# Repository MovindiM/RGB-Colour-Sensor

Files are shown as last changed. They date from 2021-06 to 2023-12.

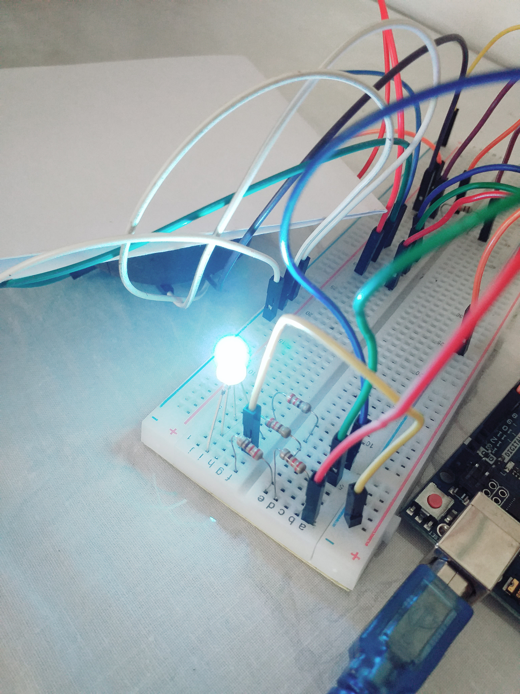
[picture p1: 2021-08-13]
Physical_Arduino_Device/photos/White.jpg

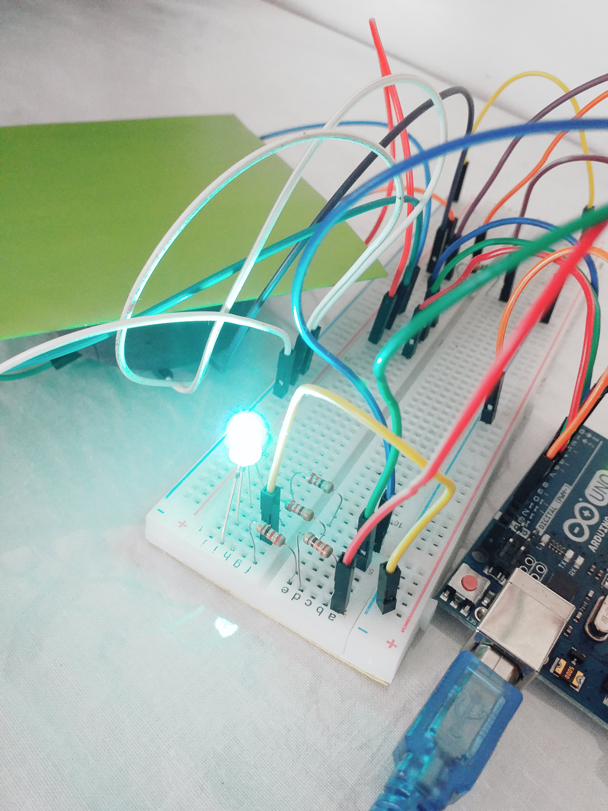
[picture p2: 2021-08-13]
Physical_Arduino_Device/photos/Green.jpg

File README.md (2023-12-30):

# RGB Colour Sensor

## Semester 2 Lab Project - GRP 14
Department of Electronic and Telecommunication Engineering  
University of Moratuwa

Welcome to the RGB Colour Sensor project repository! This project focuses on designing and implementing a colour sensor capable of detecting the colour on a surface and providing its R, G, and B values. The sensor is based on the RGB model and can find applications in industrial, medical, and security systems.

## Project Overview

In this project, we aimed to develop a versatile colour sensor with the following features:

- **Calibration Stage:** The sensor includes a calibration stage to accommodate alterations in lighting conditions.

- **Modes:**
  - **Calibration Mode (a):** Allows the user to perform calibration at the beginning.
  - **Sensing Mode (b):** Enables the sensor to detect and output the R, G, and B values of the colour on a surface.
  - **LED Illumination Mode (c):** Lights up an RGB LED based on user-defined R, G, and B values.

## Getting Started

To get started with the RGB Colour Sensor, follow these steps:

1. **Clone the Repository:**
   ```bash
   git clone https://github.com/your-username/RGB-Colour-Sensor.git

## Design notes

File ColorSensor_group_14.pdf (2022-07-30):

University of Moratuwa

EN 1093 – Laboratory Practice I

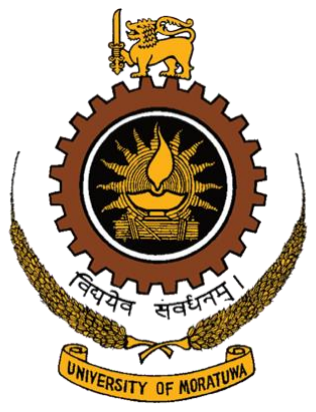
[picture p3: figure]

RGB Colour Sensor

Supervisor- Achintha Wijesinghe

This is submitted as a partial fulfillment for the module EN1093: Laboratory Practice I Department of Electronic and Telecommunication Engineering University of Moratuwa

16

th August 2021

Loshanan M. | 190363X
Luxshan S. | 190364C
Mathotaarachchi M.M. | 190388D
Mokeeshan V. | 190395V

1 | P a g e

### Abstract

Coloris- the RGB colour sensor is device that can detect the colour of any given surface. And there is a mode to light the colour using RGB LED with user given R, G, B values. The key idea is coloured objects reflect their own colour and absorb all others. This project is done by lighting a colour light source and analysing the reflected colour light from the given surface. This colour sensor is designed using ATMega microcontroller. For an input of unknown coloured surface, the result would be in the format of RGB colour model. And the colour of that surface is detected as the most dominating colour among red, green, and blue. Also, the result of RGB colour mixture can be visualised from this product using a single RGB LED and with 16*2 LCD Display.

### Table of Contents

Abstract | 1
List of Tables | 1
List of Figures | 1
1. Introduction | 2
1.1 | Task | 2
1.2 | Specifications | 2
1.3 | Scientific Literature | 2
2. Methods | 3
2.1 | Arduino 3
2.2 | Coding ATMEGA microcontroller....3
2.2.1 | Creating a function for the
Keypad: | 3
2.2.2 | Creating functions for the LCD
display and the I2C | 3

2.2.3 Creating functions for different
tasks of the algorithm | 3
2.3 | PCB Design | 4
2.3.1 | Electronic components | 4
2.3.2 | Connectors | 4
2.3.3 | PCB information | 4
2.3.4 | Main Circuit Board | 5
2.4 | Enclosure design | 5
3. Results | 6
4. Discussion | 7
5. Acknowledgement | 8
6. References | 8
7. Appendices | 9
7.1 | Appendix I-Circuit Diagram | 9
7.2 | Appendix II- PCB design | 9
7.3 | Appendix III- Enclosure Design .....10
7.4 | Appendix IV- Output | 11
7.5 | Appendix V-Algorithm | 12
| 12
7.6 | GitHub repository link- RGB Sensor
project13
7.7 Appendix VI-Atmega code | 13

### List of Tables

Table 3.1:Sensor part Readings | 6

### List of Figures

Figure 1.1:theory of colour detection | 2
Figure 2.1:LCD Display Views | 3
Figure 2.2:LDR reading principle | 4
Figure 3.1:LCD Display Views | 6
Figure 3.2: Linear mapping concept | 6
Figure 7.1:Circuit diagram with ATMega328 ..9
Figure 7.2:Schematic of the main PCB | 9
Figure 7.3:Main PCB top view (in Altium
software) | 9
Figure 7.4:PCB top layer | 9
Figure 7.5:PCB bottom layer | 9
Figure 7.6:3D view of PCB | 9
Figure 7.7:Enclosure Top view | 10
Figure 7.8:Enclosure back view | 10
Figure 7.9:Enclosure Interior-bottom part....10 Figure 7.10:Enclosure Interior top part.........10
Figure 7.11:Results- Green color | 11
Figure 7.12:Results- Blue color | 11
Figure 7.13:Results- Red Color | 11
Figure 7.14:Results- White Color | 11
Figure 7.15:Results- Violet Color | 11

### 1. Introduction

Colour detection is one of the main principles which are used to evaluate the properties of a material. Colour detection sensors are used in many industries such as food and beverage, automotive and manufacturing. In this project Coloris-the RGB colour sensor is designed using three LEDs and an LDR. It detects the colour of any surface and can light up the colour that a user wants.

The fundamental, used in this project is, objects appear coloured because they absorb some colours and reflect some other colours into human eyes. In this project colour sensor is developed by measuring the density of reflected colour light by the given-coloured object.

The most common RGB colour model is used throughout this project.

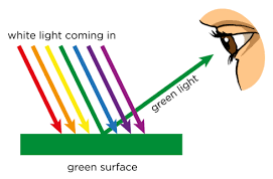
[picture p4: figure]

Figure 1.1:theory of colour detection

### 1.1 Task

- The colour sensor should sense and output the colour of a given surface.
- A calibration stage is allowed before sensing.
- There should be a mode to light a RGB LED for user given red, green, and blue values.

### 1.2 Specifications

- The sensor should contain
- a/ many LDR
- a keypad
- an LCD display
- PCBs
- enclosure
- RGB LED
- Product should be able to handle alternations in lighting conditions
- | ATMega | microcontrollers | are
recommended to use

### 1.3 Scientific Literature

After the problem was identified clearly a flowchart was developed to show objectives of the project. After that a circuit is designed using Arduino and it was coded properly. Then the circuit was developed by using physical simulations to have better results.

Then the project moved from Arduino to single ATMega microcontroller circuit. The basics of coding a microcontroller, were learned before moving the simulation to ATMega. Both ATMega and Arduino simulations were done by Proteus 8 software. Required PCB is designed using Altium software. Then using the dimensions of the PCB, the 3D enclosure was designed by Solidworks.

### 2. Methods

### 2.1 Arduino

At the beginning this project is designed using Arduino Uno. Circuits were designed in this stage and the simulations were done using Proteus software.

First LCD display is connected to Arduino and coded for displaying texts in that LCD display. Then the keypad is connected to Arduino for the purpose of changing the modes and entering the inputs for user input mode. Keypad library is used to code Arduino for using this matrix style keypad.

Next the main core part is developed using red, green, and blue LEDs and a LDR for the purpose of doing calibration and sensing. Since the pin connected to LDR should be an input pin, it was connected to an Analog pin of the Arduino.

Then there are no more free pins in Arduino to connect an RGB LED for user input mode. So, an I2C module is used to connect LCD display for minimising the required number of pins. Only two pins are enough for the working of the LCD display if the I2C is used, otherwise it requires 6 pins to connect. Then the RGB LED was attached with three PWM pins in Arduino, and the Arduino code was fully finalized.

Figure 2.1:LCD Display Views

### 2.2 Coding ATMEGA

microcontroller

As ATMEGA328P is simpler to use, with the usage of 8bit and 16bit instead of 32/64bit which are more complicated. So, here the ATMega microcontroller was used as the final design and programmed it using C.

basic libraries in C that used here.

#include <avr/io.h>

#include <util/delay.h>

#include <stdio.h>

#include <string.h>

#include <stdlib.h>

#include <math.h>

2.2.1 Creating a function for the Keypad:

- The concept behind this task is when a key is pressed the relevant circuit is completed. First the pin connected to 1

st row is made high. Then it’ll check if any of the pins connected to the columns are at the high level. After a delay of 40 ms it’ll do the same for the 2

nd row. | Just like this process takes
place in all 4 rows continuously. | If it
recognizes that a column is high, then we get the corresponding key as input.

2.2.2 Creating functions for the LCD display and the I2C

- Used datasheets and made functions for LCD and I2C separately.

2.2.3 Creating functions for different tasks of the algorithm

- As this code must do various number of
tasks, | here | several | numbers | of
functions are created earlier part of the code and used in main part. The advantages of using functions are
- Code became more simple and easily understandable.
- reduce the length of the main part of the code.
- Detecting the errors was easy.

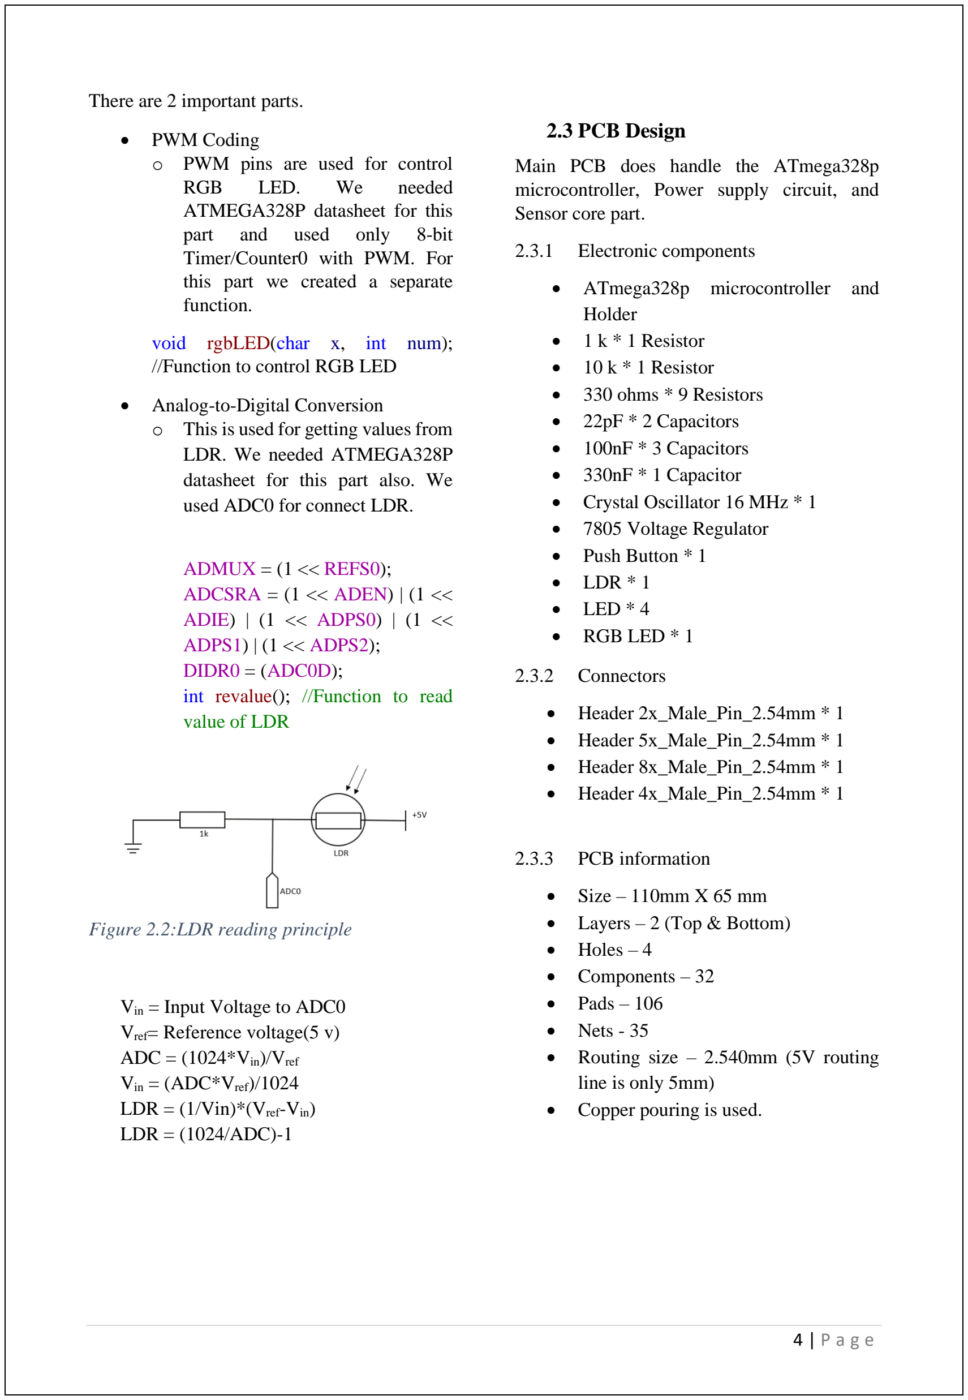
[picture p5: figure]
There are 2 important parts.; • PWM Coding • PWM pins are used for control; RGB; LED.; needed; ATMEGA328P datasheet for this; part; and; used; only; 8-bit; Timer/Counter0 with PWM. For this part we created a separate function.; void rgbLED(char x, int num); //Function to control RGB LED; • Analog-to-Digital Conversion • This is used for getting values from LDR. We needed ATMEGA328P datasheet for this part also. We used ADC0 for connect LDR.; ADMUX = (1 << REFS0); ADCSRA = (1 << ADEN) | (1 << ADIE) | (1 << ADPS0) | (1 << ADPS1) | (1 << ADPS2); DIDR0 = (ADC0D); int revalue(); //Function to read value of LDR; Figure 2.2:LDR reading principle; Vin = Input Voltage to ADC0 Vref= Reference voltage(5 v) ADC = (1024*Vin)/Vref Vin = (ADC*Vref)/1024 LDR = (1/Vin)*(Vref-Vin) LDR = (1024/ADC)-1; 2.3 PCB Design; Main PCB does handle the ATmega328p; Sensor core part.; Electronic components; • ATmega328p microcontroller and Holder; • 1 k * 1 Resistor; • 10 k * 1 Resistor; • 330 ohms * 9 Resistors; • 22pF * 2 Capacitors; • 100nF * 3 Capacitors; • 330nF * 1 Capacitor; • Crystal Oscillator 16 MHz * 1; • 7805 Voltage Regulator; • Push Button * 1; • LDR * 1; • LED * 4; • RGB LED * 1; Connectors; • Header 2x_Male_Pin_2.54mm * 1; • Header 5x_Male_Pin_2.54mm * 1; • Header 8x_Male_Pin_2.54mm * 1; • Header 4x_Male_Pin_2.54mm * 1; PCB information; • Size – 110mm X 65 mm; • Layers – 2 (Top & Bottom); • Holes – 4; • Components – 32; • Pads – 106; • Nets - 35; • Routing size – 2.540mm (5V routing line is only 5mm); • Copper pouring is used.

microcontroller, Power supply circuit, and

2.3.4 Main Circuit Board

This mainly includes the ATmega328p microcontroller, Power supply (5V Power regulator), and Sensor core part. ATmega328p microcontroller takes signals from LDR and executes appropriate color in the RGB led.

In this PCB power supply unit, first, we connect a 9V battery to the 2x_Male header pin. Then the regulating circuit converts this 9V to 5V in this purpose we use a 7805-voltage regulator, 330nF, 100nF capacitors, LED, and 330-ohm resistor. In the ATmega328p microcontroller part, there is a 22pF two capacitors, one 16 MHz crystal oscillator, one 100nF capacitor 10k resistor, and a reset button for the working
purpose | of | this | microcontroller. | This
microcontroller should be programmed by the FTDI connector with the Atmel studio programming Code for the working conditions. 8x_Male_Pin header is used to connect the keypad and the 4x_Male_Pin header is used to connect the LCD display I2C module with the main PCB board.

In the Sensor core part, here used red, green, blue led lights separately, a LDR, four 330 ohms resistors, and one 1K resistor. It located as LEDs in the circumference of the circle (1mm radius) in equal gaps. LDR is in the centre part of the circle, in the core part. two 330 ohms resistors cascade in the red LED. Because this RED color LED voltage drops (1.7V – 2V) is lower than other two-color LEDs. Also,330-ohm is connected resistors series with each green and blue LED. When the working time, the LEDs blink one by one, and the data from the color sheet is captured to the LDR in each LED blink time. And this analog
data | sends | through | the | Atmega328p
Microcontroller for identifying purposes. In the Output, RGB single LED, similarly connect their colors with 330 ohms resistors and this LED indicates the correct color of the object in the programming time.

### 2.4 Enclosure design

As a product to present in the market it is important to design an enclosure which contains the availability of fixing all the parts in an attractive and economical manner. Here for the color sensor, the enclosure was designed using Solidworks. As PCB contains both sensor part and main circuit in on a single circuit board, enclosure is in a step-down manner which will help to increase the accuracy of color sensor. After the development of body, the downloaded build-up components of 16*2 LCD Display, 4*4 Keypad and 9V battery holder and the relevant measures and spaces are added to the body. And at finally by using assembly feature of solidworks all the components were assembled as one product-Coloris Color Sensor.

The key features of the enclosure are:

- Length=210mm
- Width=120mm
- Hight=49mm
- Thickness= 2mm-5mm
- Density = 1.30 grams per cubic centimetre
- Mass = 569.99 grams
- Volume = 438.46 cubic centimetres
- | Surface | area | = | 1789.41 | square
centimetres
- material –PVC rigid
- Body color-Blue

Here as a color sensor enclosure, it must be a resistant for UV light reflection to avoid unnecessary destruction for LDR reading. So here PVC rigid material is used which is highly resistant for UV light. And more than that at the surrounding of sensor part there is black color to reduce the effect of light reflection in the reading of LDR. And finally, to present as a good outlooking device blue color is applied to the enclosure.

### 3. Results

In the working condition of the project first, LCD display shows a welcome message and then it shows operation Modes. The keypad keys show the corresponding operating modes

A – Calibration Mode

B – Sensing Mode

C – Input Keypad Values Mode

D – Reset Mode

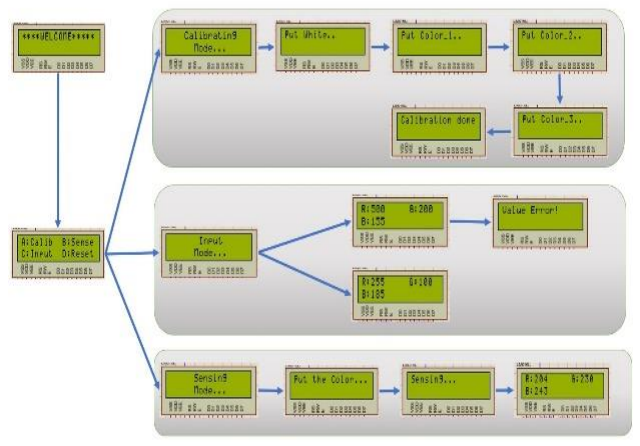
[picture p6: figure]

First, when Press “A” in the Keypad, the calibration mode will on.

Here it’ll calibrate the color cards. First, with the white color card, the sensor takes red, green, blue values to the system. Similarly, with the sequence of red color card, green color card, and the blue color card the red, green, blue values will be deducted by the system in the early stage. Then we linearly mapping (Voltage α light density) these values to get white array values and black array values. Here the below picture shows our mapping graph diagram.

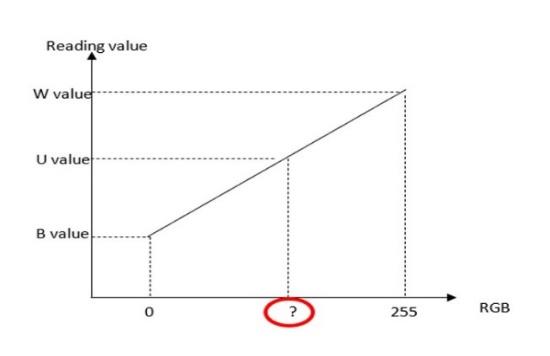
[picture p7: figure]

Figure 3.2: Linear mapping concept

According to the reading, white array red, green, and blue values are 781, 792, 625, and black array red, green, and blue values are 259, 389, 227. Then our calibration part is done.

After that press B in the Keypad to go the Sensing Mode.

Here the device will run with various of color cards to check the output. First, check the red color card in this time Lcd display shows the corresponding red, green, blue values are 223,27,41 in the 8-bit form. And the output RGB led blinks red color to indicate that color card. Similarly, check is done with green color card, blue color card, and violet color card their details are below in the table.

Table 3.1:Sensor part Readings

Color card | Red value | Green value | Blue value | RGB led blink color
Red | 223 | 27 | 41 | Red
Green | 108 | 191 | 50 | Green
Blue | 0 | 43 | 169 | Blue
White | 239 | 255 | 255 | White
Violet | 107 | 25 | 108 | Violet

Then press C in the Keypad to go to the Input Keypad Values Mode.

Here the red, green, and blue values are input in the form of 8-bit to get the corresponding output color in the RGB led. this RGB led shows the color regarding the input value and the LED screen will display the most dominating color in the respective color. For example, if we press red, green, and blue values are 255,100,50 then the output RGB led shows orange color and as most dominating value is red the screen display “red”. Sometimes if values greater than 255 (8-bit) or any alphabet letters in the keypad are input then the LCD display shows the Value Error message.

Then press D in the Keypad to go to the Reset Mode. And do again our prefer works.

The pictures in the Appendix IV shows the output result of our RGB led. The accuracy of our sensor results is presented in the pictures. The results were cross checked using the values

Figure 3.1:LCD Display Views

from | the | below | website
https://csfieldguide.org.nz/en/interactives/rgb-mixer (https://csfieldguide.org.nz/en/interactives/rgb-mixer) . The values are mostly closer to that online tool values. Therefore, the sensor is in high accuracy, and it will provide a good experience for the user.

### 4. Discussion

While doing this project, first we individually designed a device with an Arduino board. And then chose the best design and started developing it. For that, we divided the tasks and did our best to complete our tasks successfully.

Since we were beginners, we had to face a lot of problems while doing the project. Lack of experience was a main problem for us. So, we had to learn everything from basics: Arduino coding, AVR coding, Proteus Simulating, PCB designing and Enclosure designing.

The problems we encountered in the project are as follows.

- Due to the Covid-19 situation we had to do everything online, but we were able to keep good communication among group members and manage our
| project works.
- We were unable to find some components due to the pandemic
| situation.
- We had not enough pins to connect all
the | components | to
Arduino/ATMEGA328P. | So, | we
decided to connect LCD display through I2C module.
- In Proteus we had no way to give different colors to the LDR, we only had the torch LDR to get some values
| from the LDR.

Although we got correct values from our initial physical device with the Arduino board RGB LED did not give the corresponding color. We finally found that we must use higher resistant to red pin since the voltage of red pin is less than blue and green pins.

- Initially the simulation did not work as we expected for analog-to-digital converting (LDR) and PWM (RGB LED) parts. So, we had to modify the code many times.

The weekly review sessions were very helpful in clarifying our doubts and making sure whether we were moving in the right direction.

### 5. Acknowledgement

In this pandemic situation it is not an Easy task for us to finish this RGB color sensor to this far. We were novices to all the concepts of Designing and coding ideas and we faced a lot of challenges since this is our first project. There are many personnel behind the accomplishment of this project.
First, we would like to pay our gratitude to our supervisor who always encouraged self-studying and guided us whenever we needed help. The progress meetings held by our supervisor through zoom were very helpful to clear our doubts and discuss issues regarding our project.
In addition, we would like to convey our sincere gratitude to all the lecturers and instructors who were always willing to share their knowledge with us.
It is our duty to thank our ENTC family, without whom we could not have accomplished this project. Everyone in our batch helped each other and learnt everything together.
We developed team spirit working together in this project for about 3 months and all our group members gave their maximum contribution to succeed the given project.
Further, we would like to thank all the people who are not mentioned here for the great support provided even in these pandemic situations.

### 6. References

[1] https://www.sparkfun.com/datasheets/LCD/ADM1602K-NSA-FBS-3.3v.pdf (https://www.sparkfun.com/datasheets/LCD/ADM1602K-NSA-FBS-3.3v.pdf)
[2] https://www.electronicsforu.com/technology-trends/learn-electronics/16x2-lcd-pinout-diagram (https://www.electronicsforu.com/technology-trends/learn-electronics/16x2-lcd-pinout-diagram)
[3] https://www.exploreembedded.com/wiki/Basics_of_I2C_with_AVR (https://www.exploreembedded.com/wiki/Basics_of_I2C_with_AVR)
[4] http://web.csulb.edu/~hill/ee346/Lectures/20%20C++%20ATmega%20I2C%20Serial%20Comm.pdf (http://web.csulb.edu/~hill/ee346/Lectures/20%20C++%20ATmega%20I2C%20Serial%20Comm.pdf)
[5] https://circuitdigest.com/microcontroller-projects/light-intensity-measurement-using-ldr-and-atmega8 (https://circuitdigest.com/microcontroller-projects/light-intensity-measurement-using-ldr-and-atmega8)
[6] https://www.youtube.com/watch?v=POaJqnMHofo&t=409s (https://www.youtube.com/watch?v=POaJqnMHofo&t=409s)
[7] https://easyeda.com/join?type=project&key=406c4e8896c8eca25e4760e530 6c90ac (https://easyeda.com/join?type=project&key=406c4e8896c8eca25e4760e5306c90ac)
[8] https://csfieldguide.org.nz/en/interactives/rgb-mixer (https://csfieldguide.org.nz/en/interactives/rgb-mixer)

### 7. Appendices

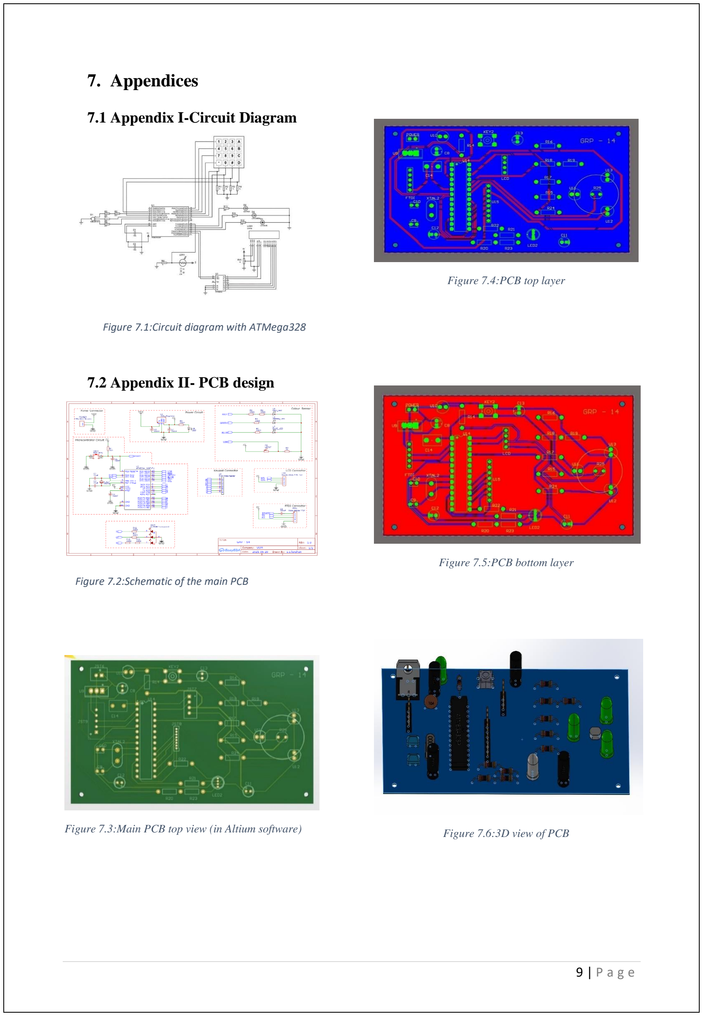
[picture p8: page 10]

### 7.1 Appendix I-Circuit Diagram

### 7.2 Appendix II- PCB design

Figure 7.3:Main PCB top view (in Altium software)

Figure 7.4:PCB top layer

Figure 7.5:PCB bottom layer

Figure 7.6:3D view of PCB

Figure 7.1:Circuit diagram with ATMega328

Figure 7.2:Schematic of the main PCB

### 7.3 Appendix III- Enclosure Design

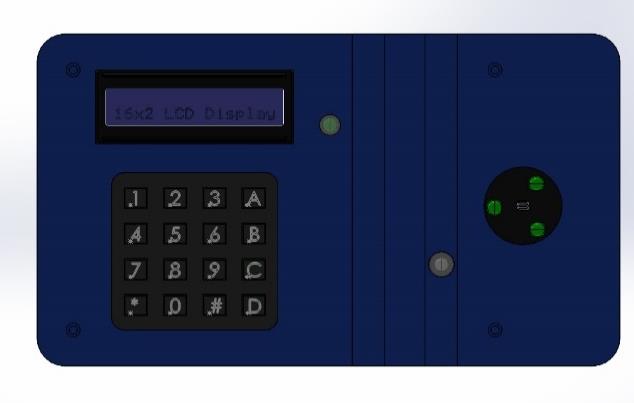
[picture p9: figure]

Figure 7.7:Enclosure Top view

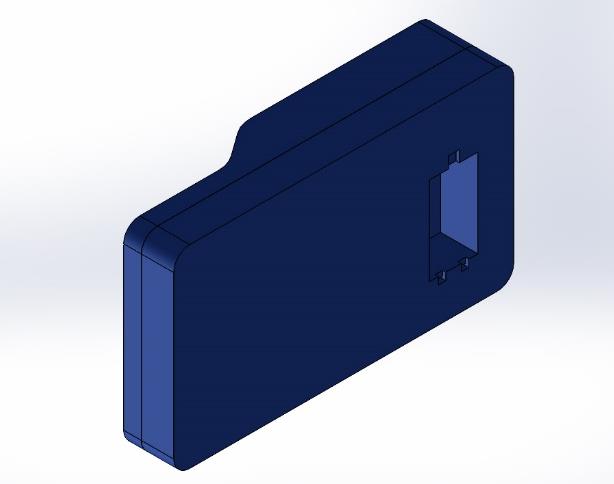
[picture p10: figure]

Figure 7.8:Enclosure back view

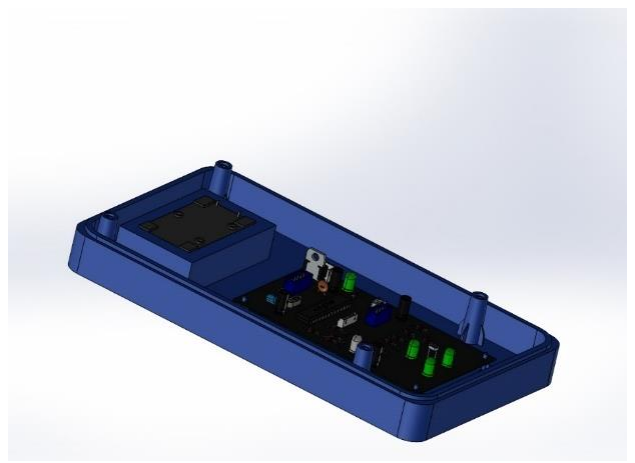
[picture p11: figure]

Figure 7.9:Enclosure Interior-bottom part

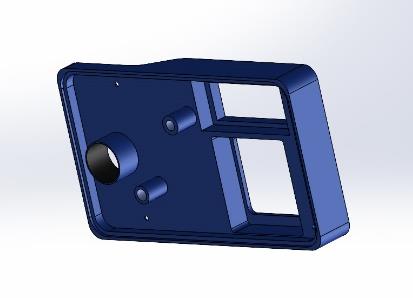
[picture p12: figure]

Figure 7.10:Enclosure Interior top part

### 7.4 Appendix IV- Output

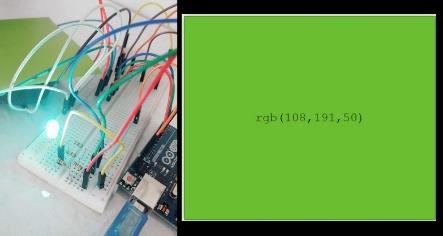
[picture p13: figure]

Figure 7.11:Results- Green color

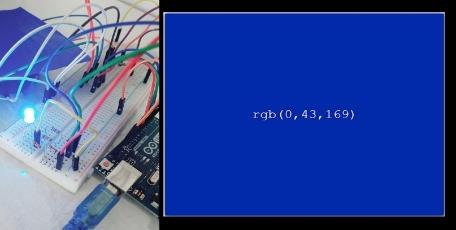
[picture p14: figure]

Figure 7.12:Results- Blue color

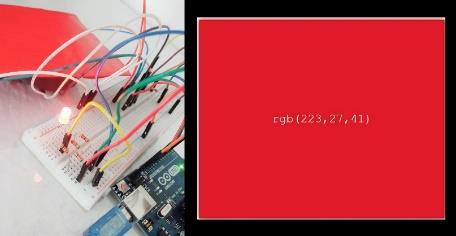
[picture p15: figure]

Figure 7.13:Results- Red Color

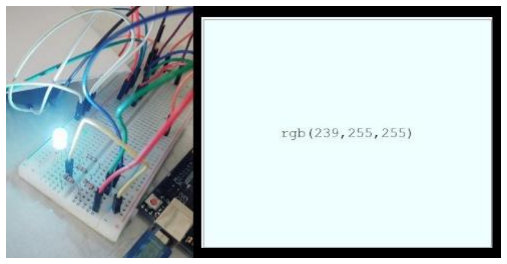
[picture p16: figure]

Figure 7.14:Results- White Color

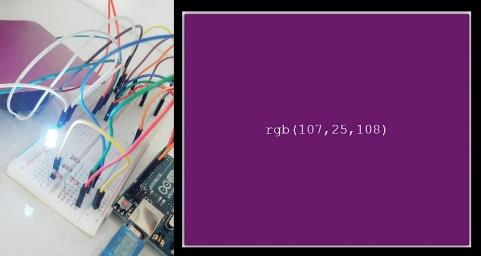
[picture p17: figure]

Figure 7.15:Results- Violet Color

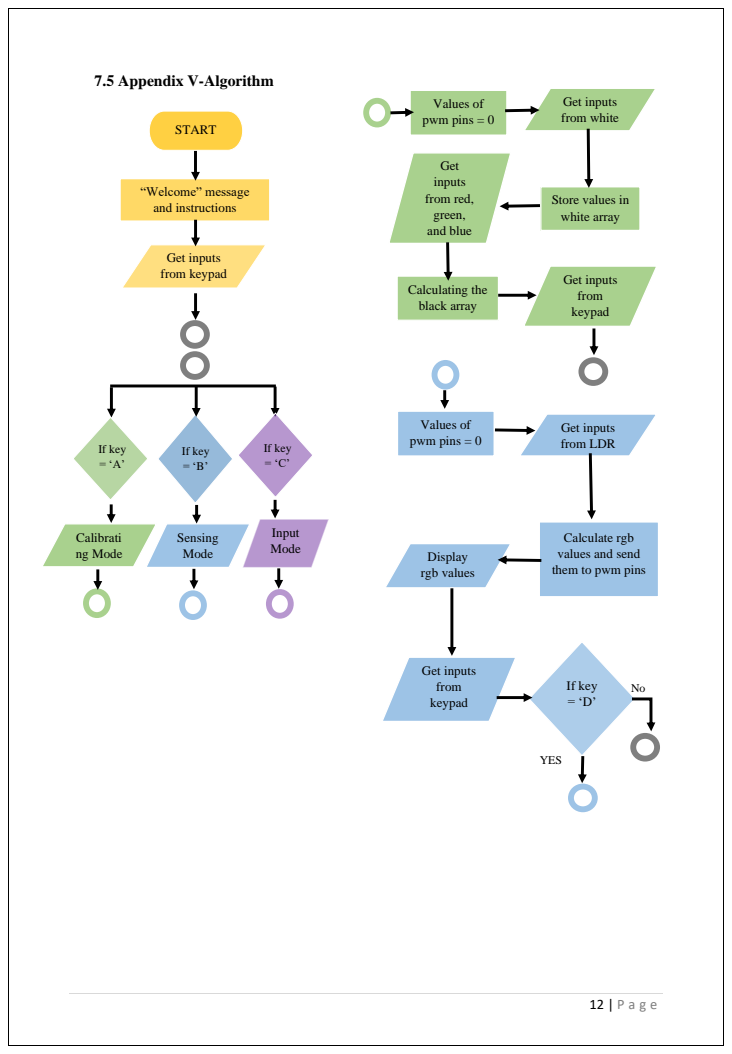
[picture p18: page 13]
7.5 Appendix V-Algorithm; Get inputs from white; Values of pwm pins = 0; Get inputs from red, green, and blue; Calculating the black array; Get inputs from keypad; START; “Welcome” message and instructions; Calibrati ng Mode; Sensing Mode; Input Mode; If key = ‘A’; If key = ‘B’; If key = ‘C’; Get inputs from LDR; Display rgb values; If key = ‘D’; YES

Store values in
white array

Calculate rgb
values and send
them to pwm pins

### 7.6 GitHub repository link- RGB

Sensor project

https://github.com/MovindiM/RGB-Colour-Sensor (https://github.com/MovindiM/RGB-Colour-Sensor)

### 7.7 Appendix VI-Atmega code

#include <avr/io.h>

#define F_CPU 8000000UL

#include <util/delay.h>

#include <stdio.h>

#include <string.h>

#include <stdlib.h>

#include <math.h>

#define Vref 5 //reference voltage for ADC

#define Res 1 //Resistor connected to LDR and GND (1k)

char* getKey(); //Function to get input from keypad

void i2cInit(); //i2c initializing Function
void i2cStart();
void i2cWrite(char x);
char i2cRead();
void lcdInit(); | //LCD Initializing Function
void toggle(); | //Latching function of LCD
void lcdCmd_hf(char v1); //Function to send half byte command to LCD
void lcdCmd(char v2); //Function to send Command to LCD void lcdDwr(char v3); //Function to send data to LCD
void lcdString(char *c); //Function to Send String to LCD void lcdString_xy(char row_1, char position, char *string_00); //Function to type string at x row y column

void inputFunc(int count, char* key, int Arr[9]); //Function to convert char inputs to int and store
void getReading(); //Function to light up r, g, and b led and take values
void sensor(int rgbArr[3]); //Function of sensing Mode
void calibrate(); //Function of calibrating Mode
void rgbCalc(int inputs[9], int rgb[3]); //Function to get RGB values from given input keys
int ldrValue(); //Function to read value of LDR
int getMax(int num_1,int num_2,int num_3); //Function to get maximum value
int mapValue(int value, int maximum, int minimum); //Function to map LDR value to integer number
void rgbLED(char x, int num); //Function to control RGB LED int checkError(int Arr[3]); //Function to check input rgb values are less than 255
void sensorOutput(int whiteArr[3], int blackArr[3], int rgbArr[3]); //Function of output (sensor Mode)
void pwmLow(); //Function of making the PWM pins(connected to rgb led) low
int inputCount = 0; //global variable to count inputs in input Mode
int main(void)
{
DDRB = 0XCF; //PORTB4 and PORTB5 are inputs DDRD = 0XE8; //PORTD0, PORTD1, PORTD2 and PORTD4 are inputs
DDRC = 0XFE; //PORTC0 is input others are output

ADMUX = (1 << REFS0); // setting the reference of ADC (connected to ADC0 --> 0000)
ADCSRA = (1 << ADEN) | (1 << ADIE) | (1 <<
ADPS0) | (1 << ADPS1) | (1 << ADPS2); //ADC enable ADC
interrupt enable ADC pre-scaler selection to 128
DIDR0 = (ADC0D); //Digital input disable

int inputMode = 0; //Used to know whether input mode is selected
int startInput = 0; //Used to stop take numbers as inputs after getting 9 numbers in input mode
int sensingMode = 0; //Used to know whether sensing mode is selected

Count = 0

Count = count+1

Get inputs
from
keypad

Values of
pwm pins

If key
= ‘D’

Convert char to
int and store

Calculate rgb values
from given inputs
and send rgb values
to pwm pins Count = 0

If
key is not
equal to ‘A’,
‘B’, ‘C’, ‘D’,
‘*’ or ’#’

If
count = 9

YES

No

No

YES int inputArr[9] = {0,0,0,0,0,0,0,0,0}; //Array to store input values
int whiteArr[3] = {0,0,0}; //Array to store highest values(calibrating)
int blackArr[3] = {0,0,0}; //Array to store lowest values(calibrating)
int rgbArr_1[3] = {0,0,0}; //Array to store RGB values for sensing mode
int rgbArr_2[3] = {0,0,0}; //RGB values for input giving mode

i2cInit();
i2cStart();
i2cWrite(0X70);
lcdInit();

lcdString("****WELCOME*****");//welcome message
_delay_ms(2500);
lcdCmd(0x01);//clear LCD
lcdString_xy(0,0,"A:Calib"); lcdString_xy(0,9,"B:Sense"); lcdString_xy(1,0,"C:Input"); lcdString_xy(1,9,"D:Reset");

while (1)
{
char* key = getKey(); //get key from key pad
if (strcmp(key,"NO_KEY")!=0) //checking key has been given or not {
if (strcmp(key,"A")==0)
//Calibrating Mode
{
pwmLow();
int inputMode = 0;
int sensingMode =
0;

lcdCmd(0x01);//clear LCD

lcdCmd(0x0C);//cursor off

lcdString_xy(0,3,"Calibrating");

lcdString_xy(1,5,"Mode..."); _delay_ms(1000);

calibrate(whiteArr,blackArr);//calibrating }
else if (strcmp(key,"B")==0) //Sensing Mode
{
pwmLow();
inputMode = 0;
sensingMode = 1;
lcdCmd(0x01);

lcdCmd(0x0C);//cursor off

lcdString_xy(0,5,"Sensing");

lcdString_xy(1,5,"Mode..."); _delay_ms(1000);

sensor(rgbArr_1);//sensing

sensorOutput(whiteArr,blackArr,rgbArr_1);//output }
else if (strcmp(key,"C")==0) //Input Mode (select the input Mode)
{
pwmLow();
inputMode = 1;

startInput = 1;
sensingMode = 0;
inputCount = 0;
lcdCmd(0x01);
lcdCmd(0x0C);

lcdString_xy(0,6,"Input");

lcdString_xy(1,5,"Mode..."); _delay_ms(1000);
lcdCmd(0x01);
lcdString("R:");

lcdCmd(0X0E);//cursor on
}

else if (strcmp(key,"D")==0) //Used to reset values in sensing and input modes {
pwmLow();
if (sensingMode ==
1)//reset sensor values
{

sensor(rgbArr_1);//sensing

sensorOutput(whiteArr,blackArr,rgbArr_1);//output }
else if
(inputMode==1)//reset inputs
{

startInput = 1;
inputCount = 0;
lcdCmd(0x01);
lcdString("R:");
lcdCmd(0X0E);//Cursor on
}
}

else if ((strcmp(key,"#")!=0) && (strcmp(key,"*")!=0) && (inputMode==1) && (startInput==1)) //if input mode selected and key is a number {
//get inputs

inputFunc(inputCount,key,inputArr); inputCount++;
if (inputCount==9)
{

inputCount = 0;

startInput = 0;

lcdCmd(0x0C); //cursor off

_delay_ms(1000);

rgbCalc(inputArr,rgbArr_2);//calculate rgb values int Error
= checkError(rgbArr_2);//check error
if (Error
== 0)
{

rgbLED('r',rgbArr_2[0]); //Red

rgbLED('g',rgbArr_2[1]); //Green

rgbLED('b',rgbArr_2[2]); //Blue }
else
{

lcdCmd(0x01);

lcdString("Value Error!"); //if value>255 }
}
}
}
}
}

//get inputs from keypad
char* getKey()
{
char* key = "NO_KEY";
PORTB = 0X01; //1st row
if (PINB == 0X11)
{
key = "1";
}
if (PINB == 0X21)
{
key = "2";
}
if ((PINB == 0X01) && ((PIND & 0X04) == 0X04)) {
key = "3";
}
if ((PINB == 0X01) && ((PIND & 0X10) == 0X10)) {
key = "A";
}
_delay_ms(40);

PORTB = 0X02; //2nd row
if (PINB == 0X12)
{
key = "4";
}
if (PINB == 0X22)
{
key = "5";
}
if ((PINB == 0X02) && ((PIND & 0X04) == 0X04)) {
key = "6";
}
if ((PINB == 0X02) && ((PIND & 0X10) == 0X10)) {
key = "B";
}
_delay_ms(40);

PORTB = 0X04; //3rd row
if (PINB == 0X14)
{
key = "7";
}
if (PINB == 0X24)
{
key = "8";
}
if ((PINB == 0X04) && ((PIND & 0X04) == 0X04)) {
key = "9";
}
if ((PINB == 0X04) && ((PIND & 0X10) == 0X10)) {
key = "C";
}
_delay_ms(40);

PORTB = 0X08; //4th row
if (PINB == 0X18)
{

key = "*";
}
if (PINB == 0X28)
{
key = "0";
}
if ((PINB == 0X08) && ((PIND & 0X04) == 0X04)) {
key = "#";
}
if ((PINB == 0X08) && ((PIND & 0X10) == 0X10)) {
key = "D";
}
_delay_ms(40);
return key;
}

void i2cInit(){
TWBR = 0x62; // Baud rate is set by calculating TWCR = (1<<TWEN); //Enable I2C
TWSR = 0x00; //Pre-scaler set to 1
}

//Start condition
void i2cStart(){
TWCR = (1<<TWINT) | (1<<TWEN) |
(1<<TWSTA); | //start condition
while (!(TWCR & (1<<TWINT))); //check for start condition

}

//I2C stop condition
void i2cWrite(char x){
TWDR = x; //Move value to I2C
TWCR = (1<<TWINT) | (1<<TWEN); //Enable I2C
and clear interrupt
while (!(TWCR &(1<<TWINT)));
}

char i2cRead(){
TWCR = (1<<TWEN) | (1<<TWINT); //Enable
I2C and clear interrupt
while (!(TWCR & (1<<TWINT))); //Read successful with all data received in TWDR
return TWDR;
}

void toggle()
{
TWDR |= 0x02; //PIN En de la LCD en = 1; Latching data in to LCD data register using High to Low signal
TWCR = (1<<TWINT) | (1<<TWEN); //Enable I2C
and clear interrupt
while (!(TWCR &(1<<TWINT))); _delay_ms(1);
TWDR &= ~0x02; //PIN del Enable de la LCD en = 0;
TWCR = (1<<TWINT) | (1<<TWEN); //Enable I2C
and clear interrupt
while (!(TWCR &(1<<TWINT)));
}

void lcdCmd_hf(char v1)
{
TWDR &=~0x01; //PIN RS de la LCD rs = 0; Selecting register as Command register
TWCR = (1<<TWINT) | (1<<TWEN); //Enable I2C
and clear interrupt
while (!(TWCR &(1<<TWINT)));
TWDR &= 0x0F; //clearing the Higher 4 bits
TWCR = (1<<TWINT) | (1<<TWEN); //Enable
I2C and clear interrupt
while (!(TWCR &(1<<TWINT)));

TWDR |= (v1 & 0xF0); //Masking higher 4 bits and sending to LCD
TWCR = (1<<TWINT) | (1<<TWEN); //Enable
I2C and clear interrupt
while (!(TWCR &(1<<TWINT)));
toggle();
}

//Send command to LCD
void lcdCmd(char v2)
{
TWDR&=~0x01; //rs = 0; Selecting register as command register
TWCR = (1<<TWINT) | (1<<TWEN); //Enable I2C
and clear interrupt
while (!(TWCR &(1<<TWINT)));
TWDR &= 0x0F; //clearing the Higher 4 bits
TWCR = (1<<TWINT) | (1<<TWEN); //Enable I2C
and clear interrupt
while (!(TWCR &(1<<TWINT)));
TWDR |= (v2 & 0xF0); //Masking higher 4 bits and sending to LCD
TWCR = (1<<TWINT) | (1<<TWEN); //Enable I2C
and clear interrupt
while (!(TWCR &(1<<TWINT)));
toggle();

TWDR &= 0x0F; //clearing the Higher 4 bits
TWCR = (1<<TWINT) | (1<<TWEN); //Enable I2C
and clear interrupt
while (!(TWCR &(1<<TWINT)));
TWDR |= ((v2 & 0x0F)<<4); //Masking lower 4 bits and sending to LCD
TWCR = (1<<TWINT) | (1<<TWEN); //Enable I2C
and clear interrupt
while (!(TWCR &(1<<TWINT)));
toggle();
}

//send data to LCD
void lcdDwr(char v3)
{
TWDR|=0x01; | //rs = 1; Selecting register as
command register
TWCR = (1<<TWINT) | (1<<TWEN); //Enable I2C
and clear interrupt
while (!(TWCR &(1<<TWINT)));
TWDR &= 0x0F; //clearing the Higher 4 bits
TWCR = (1<<TWINT) | (1<<TWEN); //Enable I2C
and clear interrupt
while (!(TWCR &(1<<TWINT)));
TWDR |= (v3 & 0xF0); //Masking higher 4 bits and sending to LCD
TWCR = (1<<TWINT) | (1<<TWEN); //Enable I2C
and clear interrupt
while (!(TWCR &(1<<TWINT)));
toggle();

TWDR &= 0x0F; //clearing the Higher 4 bits
TWCR = (1<<TWINT) | (1<<TWEN); //Enable I2C
and clear interrupt
while (!(TWCR &(1<<TWINT)));
TWDR |= ((v3 & 0x0F)<<4); //Masking lower 4 bits and sending to LCD
TWCR = (1<<TWINT) | (1<<TWEN); //Enable I2C
and clear interrupt
while (!(TWCR &(1<<TWINT)));
toggle();
}

//initiating LCD
void lcdInit()
{
lcdCmd_hf(0x30); //Sequence for initializing LCD lcdCmd_hf(0x30); //Sequence for initializing LCD lcdCmd_hf(0x20); //Sequence for initializing LCD lcdCmd(0x28); //Selecting 16 x 2 LCD in 4Bit mode lcdCmd(0x0C); //Display ON Cursor OFF lcdCmd(0x01); //Clear display
lcdCmd(0x06); //Cursor Auto Increment lcdCmd(0x80); //1st line 1st location of LCD }

//send string to LCD
void lcdString(char *c)
{
while(*c != 0) //Wait till all String are passed to LCD lcdDwr(*c++); //Send the String to LCD
}

//sent string to x row y column of LCD
void lcdString_xy(char row_1, char position, char *string_00) {
if ((row_1 == 0) && (position<16))
{
lcdCmd((position & 0x0F) | 0x80);
lcdString(string_00);
}
else if ((row_1 == 01) && (position<16))
{
lcdCmd((position & 0x0F) | 0xC0);
lcdString(string_00);
}
}

//convert char input to int and store(used in input mode) void inputFunc(int count, char* key, int Arr[9])
{
lcdString(key);
_delay_ms(300);
Arr[count] = atoi(key);
if (count==2)
{
lcdString_xy(0,10,"G:");
}
else if (count==5)
{
lcdString_xy(1,0,"B:");
}
}

//getting LDR resistant
int ldrValue()
{
//float Vin = voltage at ADC pin
float LDR; //resistant of LDR
ADCSRA |= (1 << ADSC); // ADC start conversion _delay_ms(100);
/*ADC = (Vin*1024)/Vref
Vin = (ADC*Vref)/1024
LDR = (1/Vin)*(Vref-Vin)
LDR = (1024/ADC)-1*/
LDR = (1024/ADC)-1;
int x = round(LDR);
return x;
}

//light up r, g, b led and take values(used in both calibration and sensor mode)
void getReading(int rgbArr[3])
{
PORTC |= 0X02; //light red led _delay_ms(300);
//get readings
rgbArr[0] = ldrValue();
PORTC &= 0XFD; //off red led _delay_ms(1000);
PORTC |= 0X04; //light green led _delay_ms(300);
//get readings

rgbArr[1] = ldrValue();
PORTC &= 0XFB; //off green led _delay_ms(1000);
PORTC |= 0X08; //light blue led _delay_ms(300);
//get readings
rgbArr[2] = ldrValue();
PORTC &= 0XF7; //off blue led }

//Sensing Mode
void sensor(int rgbArr[3])
{
lcdCmd(0x01); //clear LCD display lcdString("Put the Color..."); _delay_ms(2000);
lcdCmd(0x01);
lcdString("Sensing...");
getReading(rgbArr);
_delay_ms(50);
}

//get maximum
int getMax(int num_1,int num_2,int num_3)
{
int Maximum = 0;
int Arr[3] = {num_1,num_2,num_3}; for (int i=0;i<3;i++)
{
if (Arr[i]>Maximum)
{
Maximum = Arr[i];
}
}
return Maximum;
}

//Function of calibrating mode
void calibrate(int whiteArr[3],int blackArr[3]) {
int Arr_1[3] = {0,0,0};
int Arr_2[3] = {0,0,0};
int Arr_3[3] = {0,0,0};
lcdCmd(0x01);
lcdString("Put White.."); //white _delay_ms(2000);
lcdCmd(0x01);
lcdString("Calibrating...");
_delay_ms(10);
getReading(whiteArr);//lighting up LEDs and sensing
lcdCmd(0x01);
lcdString("Put Color_1.."); //Color1 _delay_ms(2000);
lcdCmd(0x01);
lcdString("Calibrating...");
_delay_ms(10);
getReading(Arr_1);//lighting up LEDs and sensing lcdCmd(0x01);
lcdString("Put Color_2..");
_delay_ms(2000);
lcdCmd(0x01);
lcdString("Calibrating...");
_delay_ms(10);
getReading(Arr_2);//lighting up LEDs and sensing lcdCmd(0x01);
lcdString("Put Color_3..");
_delay_ms(2000);
lcdCmd(0x01);
lcdString("Calibrating...");
_delay_ms(10);
getReading(Arr_3);//lighting up LEDs and sensing lcdCmd(0x01);
lcdString("Calibration done");

//light intensity and resistant of LDR are inversely proportional. to get darkest values maximum resistant should be taken
blackArr[0] = getMax(Arr_1[0],Arr_2[0],Arr_3[0]); blackArr[1] = getMax(Arr_1[1],Arr_2[1],Arr_3[1]); blackArr[2] = getMax(Arr_1[2],Arr_2[2],Arr_3[2]); }

//Function to calculate RGB values from given inputs
void rgbCalc(int inputs[9], int rgb[3])
{
rgb[0] = (inputs[0]*100)+(inputs[1]*10)+inputs[2]; rgb[1] = (inputs[3]*100)+(inputs[4]*10)+inputs[5]; rgb[2] = (inputs[6]*100)+(inputs[7]*10)+inputs[8]; }

//Function to map LDR value to integer number
int mapValue(int value, int maximum, int minimum)
{
float x=255.00;
int a = (maximum-minimum);
int b = (maximum-value);
float c = x*b/a;
int y = round(c);
if (y<0)
{
y = 0;
}
return y;
}

//Function to control RGB LED
void rgbLED(char x, int num)
{
TCCR0B = (1 << CS00) | (1 << CS01); //pre scaler
64 ( for OC0A and OC0B)
TCCR2B = (1 << CS20) | (1 << CS21); //pre scaler
64 ( for OC2B)

if (x == 'r')
{
TCCR2A = (1 << WGM21) | (1 <<
WGM20) | (1 << COM2B1); // fast PWM non inverting
OCR2B = num;
}
else if (x == 'g')
{
TCCR0A |= (1 << WGM01) | (1 <<
WGM00) | (1 << COM0B1); // fast PWM non inverting
OCR0B = num;
}
else if (x == 'b')
{
TCCR0A |= (1 << WGM01) | (1 <<
WGM00) | (1 << COM0A1); //fast PWM non inverting
OCR0A = num;
}
}

//Function to check input rgb values are less than 255 int checkError(int Arr[3])
{
int Error = 0;
for (int i = 0; i<3; i++)
{
if (Arr[i] > 255)
{
Error = 1;
break;
}
}
return Error;
}

//Function of output (sensor Mode)

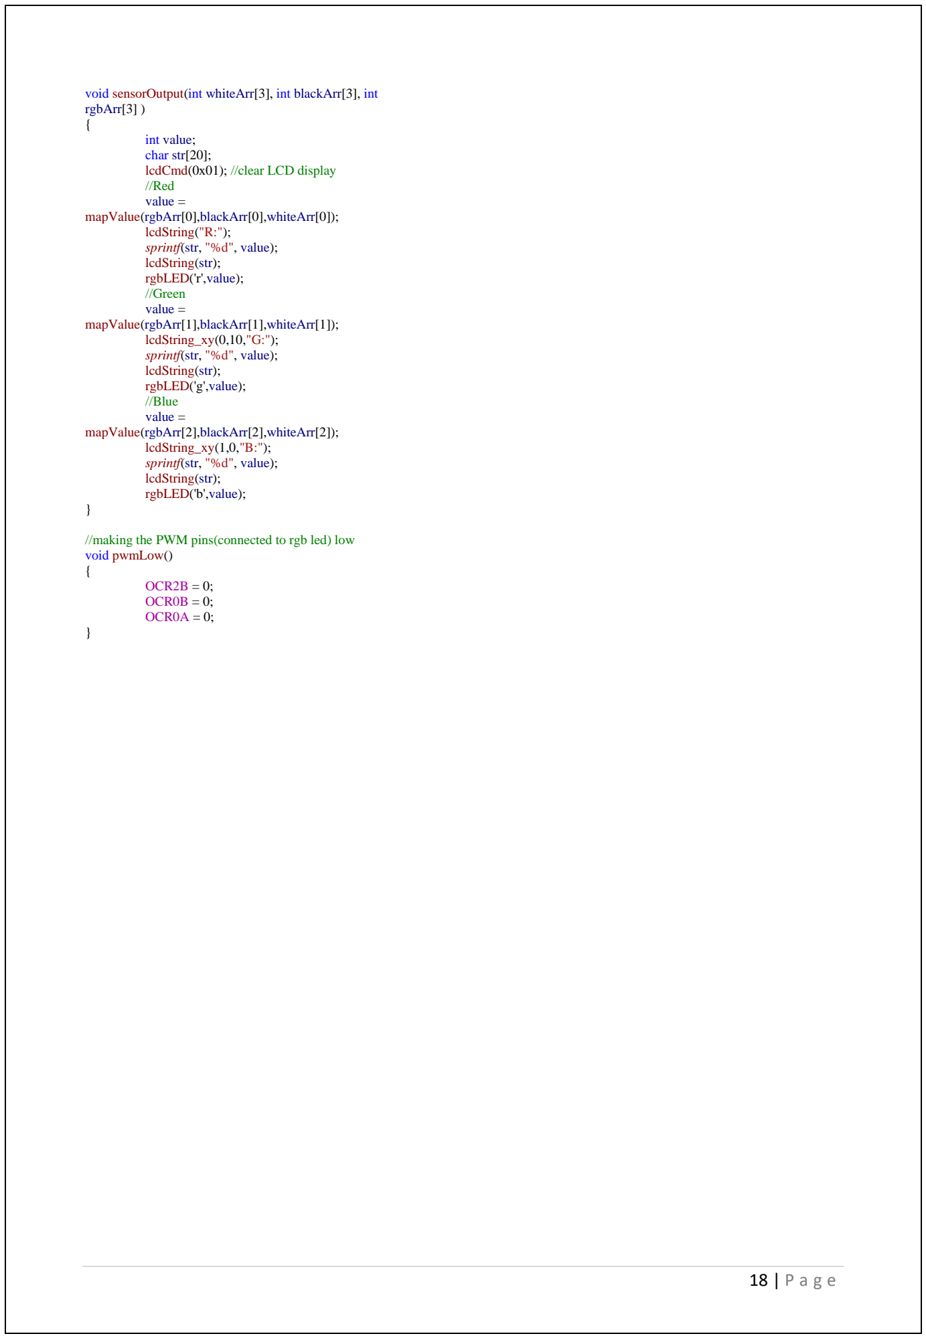
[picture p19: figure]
rgbArr[3] ) {; int value; char str[20]; lcdCmd(0x01); //clear LCD display //Red value =; lcdString("R:"); sprintf(str, "%d", value); lcdString(str); rgbLED('r',value); //Green value =; lcdString_xy(0,10,"G:"); sprintf(str, "%d", value); lcdString(str); rgbLED('g',value); //Blue value =; lcdString_xy(1,0,"B:"); sprintf(str, "%d", value); lcdString(str); rgbLED('b',value);; void pwmLow() {; OCR2B = 0; OCR0B = 0; OCR0A = 0;

void sensorOutput(int whiteArr[3], int blackArr[3], int

mapValue(rgbArr[0],blackArr[0],whiteArr[0]);

mapValue(rgbArr[1],blackArr[1],whiteArr[1]);

mapValue(rgbArr[2],blackArr[2],whiteArr[2]);

//making the PWM pins(connected to rgb led) low

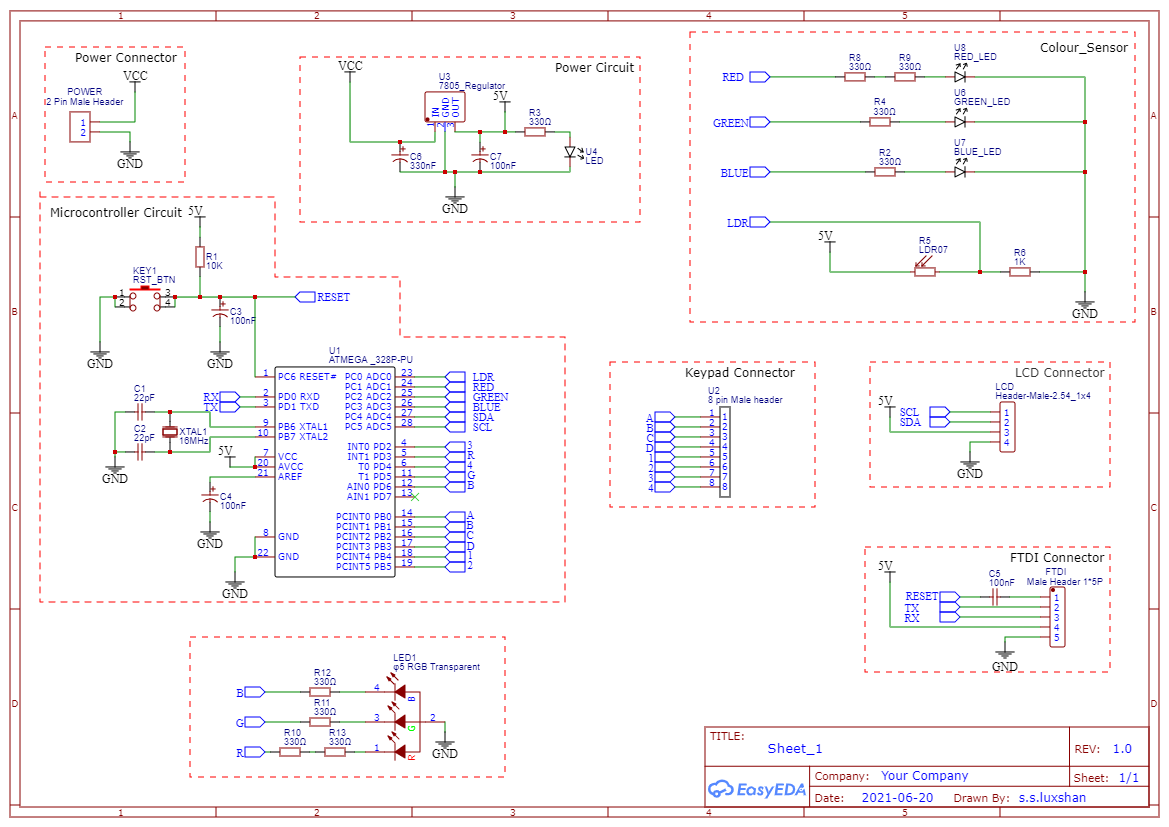
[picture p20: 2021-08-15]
PCB Final/Final Works/PCB_Schematic.png

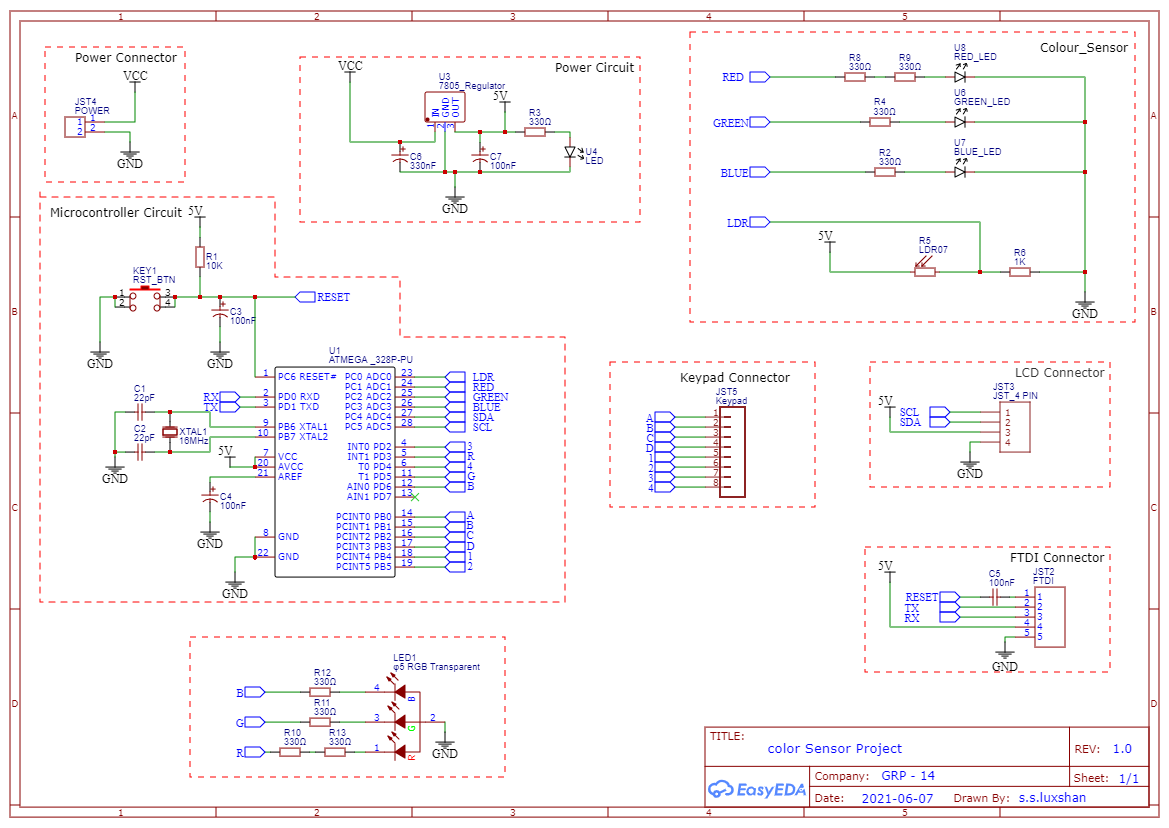
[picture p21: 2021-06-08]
PCB Final/Schematic_color Sensor Grp 14.png

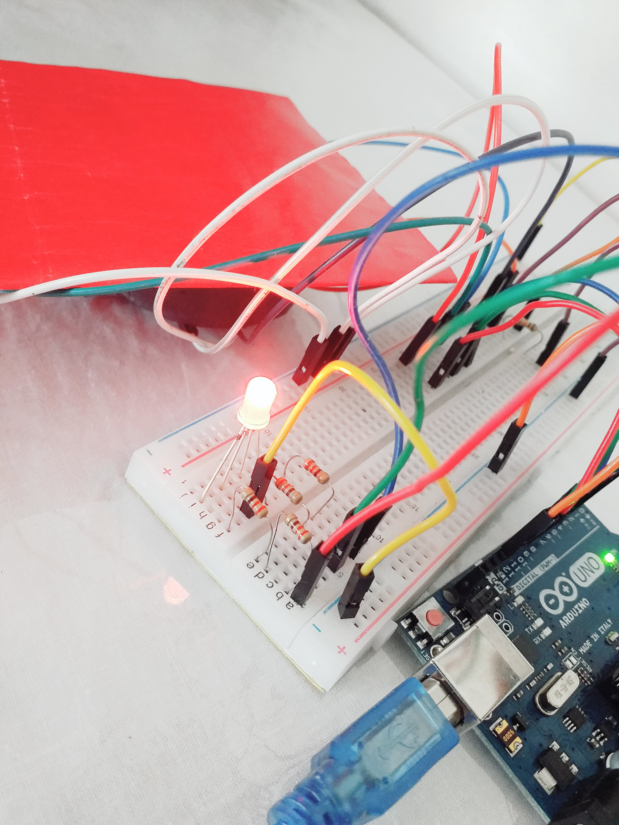
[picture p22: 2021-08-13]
Physical_Arduino_Device/photos/Red.jpg

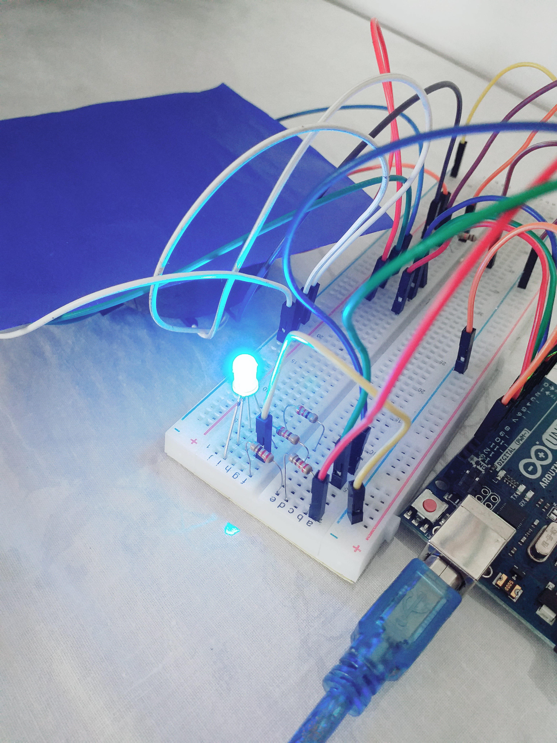
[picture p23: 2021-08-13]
Physical_Arduino_Device/photos/Blue.jpg

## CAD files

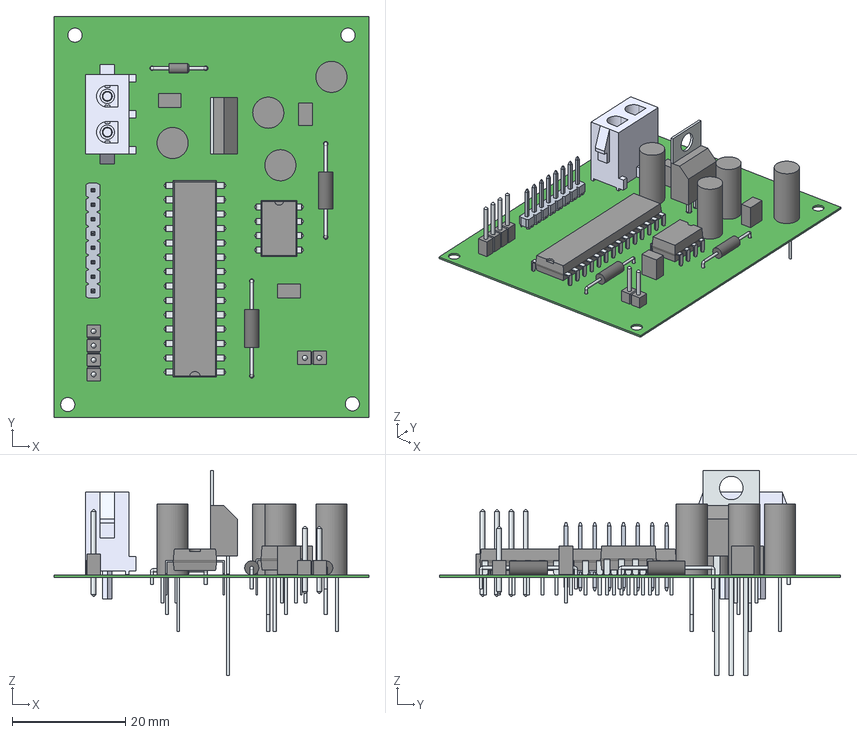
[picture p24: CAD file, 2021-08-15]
PCB Final/Final Works/PCB Main.step
55.6 x 70.9 x 36.3 mm
LeadsArray x 2
SimpleBody x 6
PinsArrayLR x 2
Tab
PinsArray
Leads x 6
Pin1 x 4
Pin2 x 4

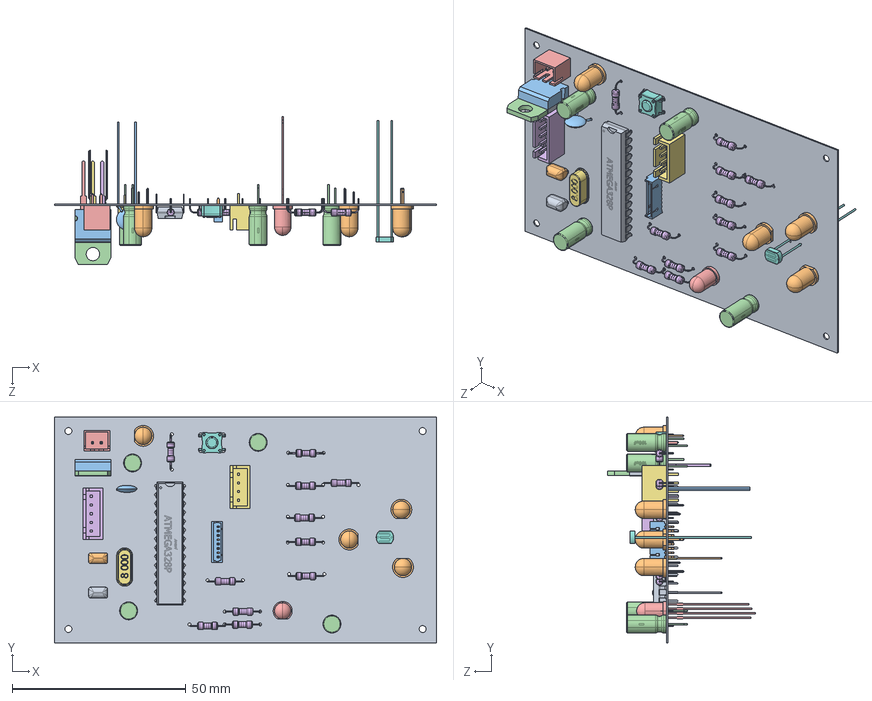
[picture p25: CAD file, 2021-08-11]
enclosure/1.SLDASM
110.0 x 65.0 x 42.5 mm
pins.step
regulator.step
regulator-0.step
regulator-1.step
regulator-2.step
regulator-3.step
regulator-4.step
regulator-5.step
regulator-6.step
regulator-7.step
JST_B2B-XH-A_Through-hole_shrouded_header_top_entry_type.step
B5B-XH-A.step
B4B-XH-A.step
Push_Button_Tactile.step
RDER71H105K2M1C03A.step
RDER71H105K2M1C03A_1984339275.step
disccap.step
100uF.step x 4
CA_GRB_LED_5mm.step
axial_resistor_6mm.step x 11
crystal_oscillator.step
Part7.step
ATMEGA328p.step
LED_GREEN_5MM.step x 4

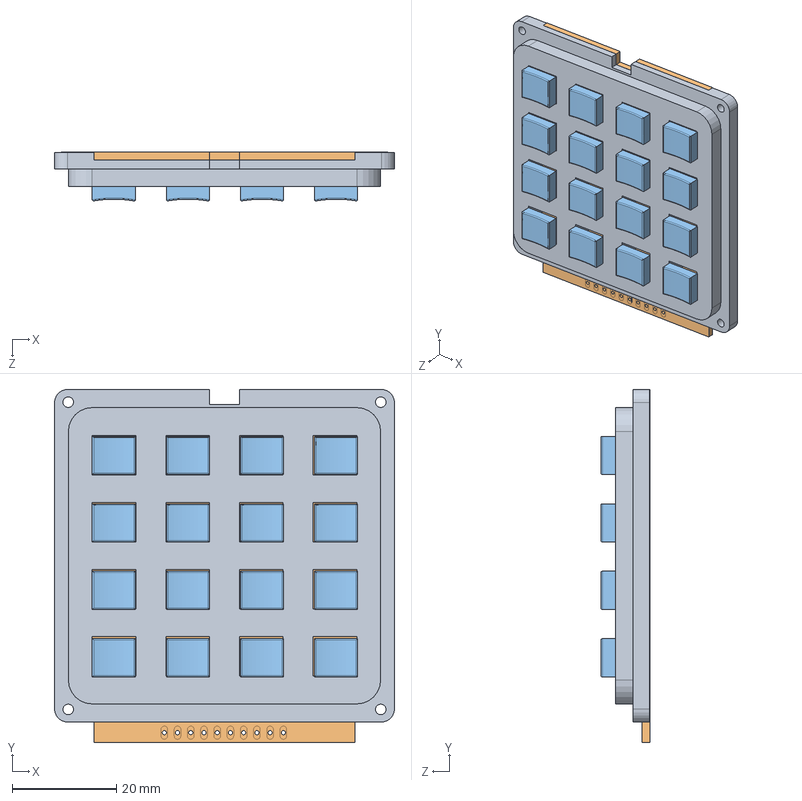
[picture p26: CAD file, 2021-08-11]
enclosure/!keypad.SLDASM
65.3 x 67.8 x 9.40 mm
plastic_base
pcb
key x 16

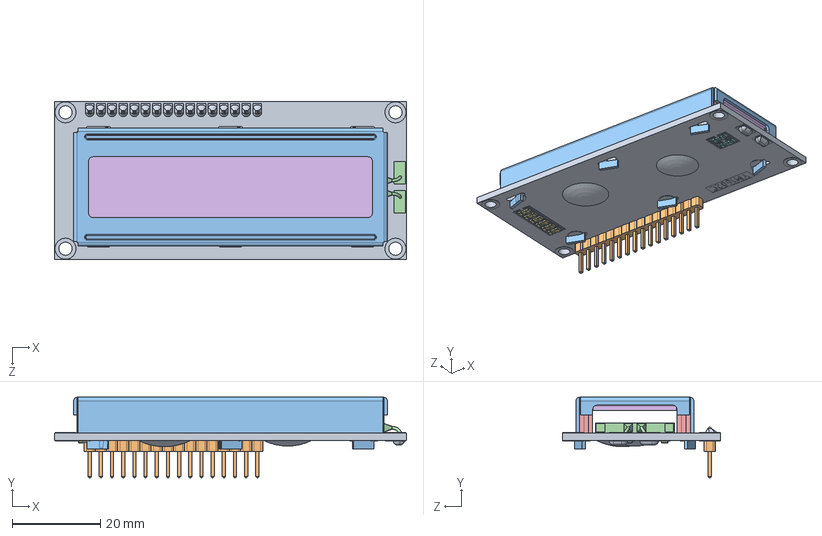
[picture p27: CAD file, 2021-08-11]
enclosure/LCD.SLDASM
80.0 x 18.3 x 36.0 mm
pcbboard
16pin_header__
lcd window
backlight
conductor x 2
liquid crystal grabcad
smt_resistor222 x 6
smt_resistor101 x 2

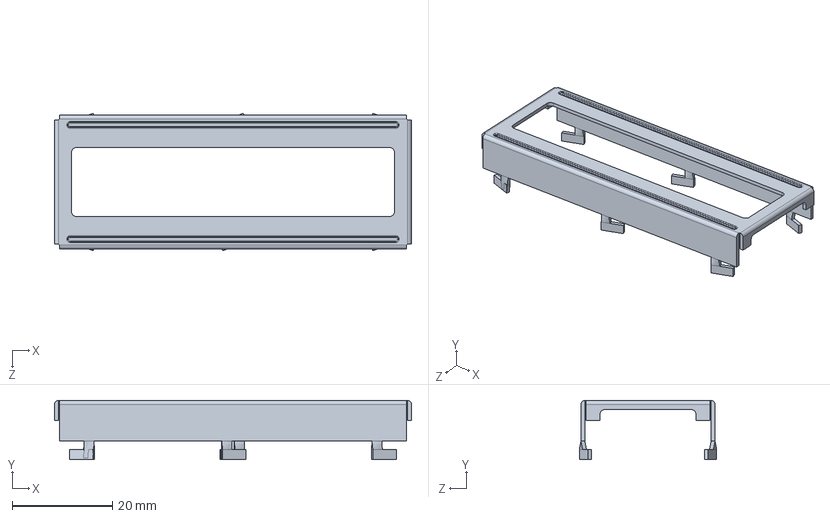
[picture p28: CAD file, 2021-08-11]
enclosure/lcd window.SLDPRT
71.3 x 11.8 x 27.4 mm

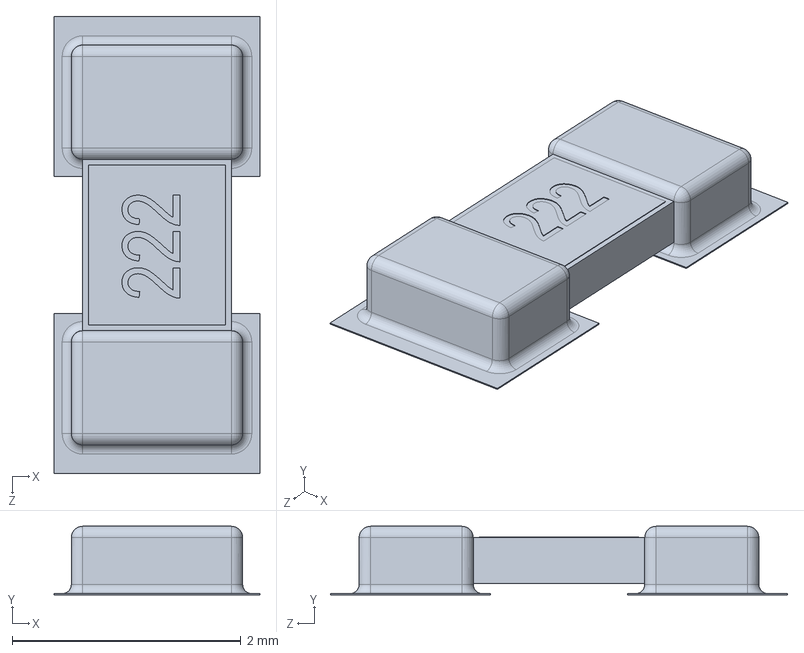
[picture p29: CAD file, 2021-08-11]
enclosure/smt_resistor222.sldprt
1.80 x 0.6 x 4.00 mm

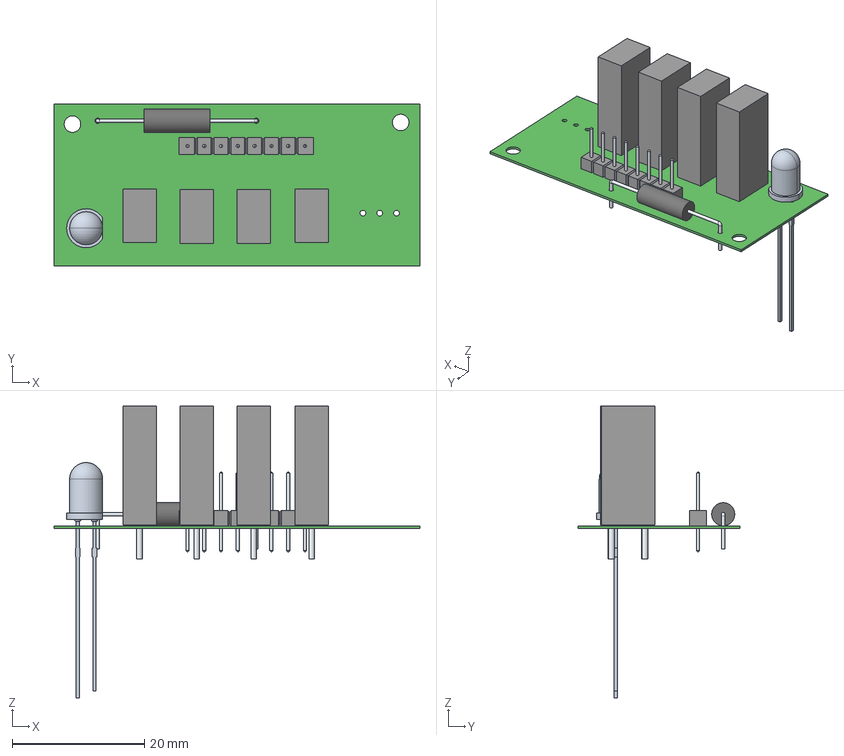
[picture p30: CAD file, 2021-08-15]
PCB Final/Final Works/PCB_Switch.step
55.4 x 24.5 x 44.1 mm
SimpleBody
LeadsArray
Leads x 8

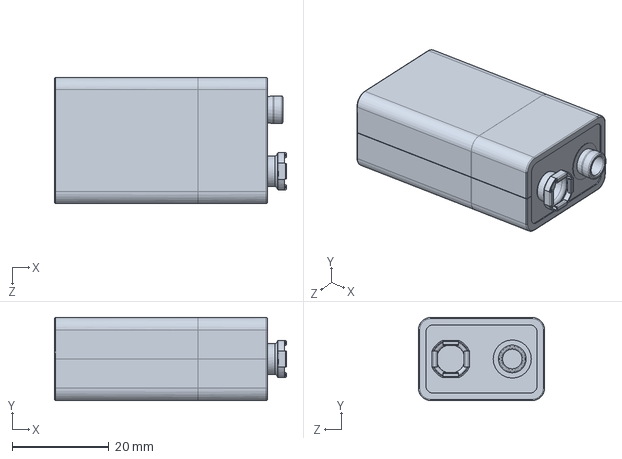
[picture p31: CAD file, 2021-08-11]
enclosure/9v battery.stp.SLDPRT
47.9 x 17.1 x 26.0 mm

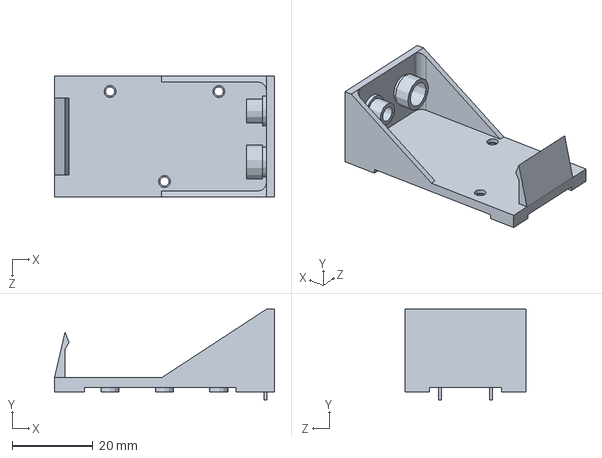
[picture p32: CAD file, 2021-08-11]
enclosure/BATTARY HOLDER.SLDPRT
54.6 x 22.5 x 30.0 mm

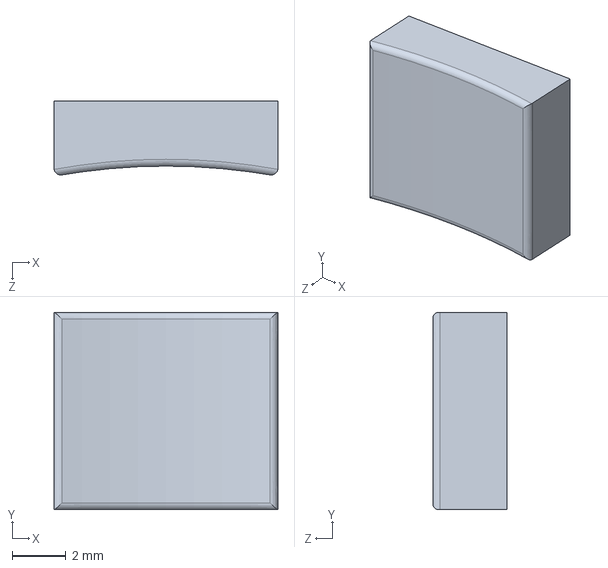
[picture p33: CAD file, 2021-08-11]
enclosure/key.SLDPRT
8.31 x 7.32 x 2.74 mm

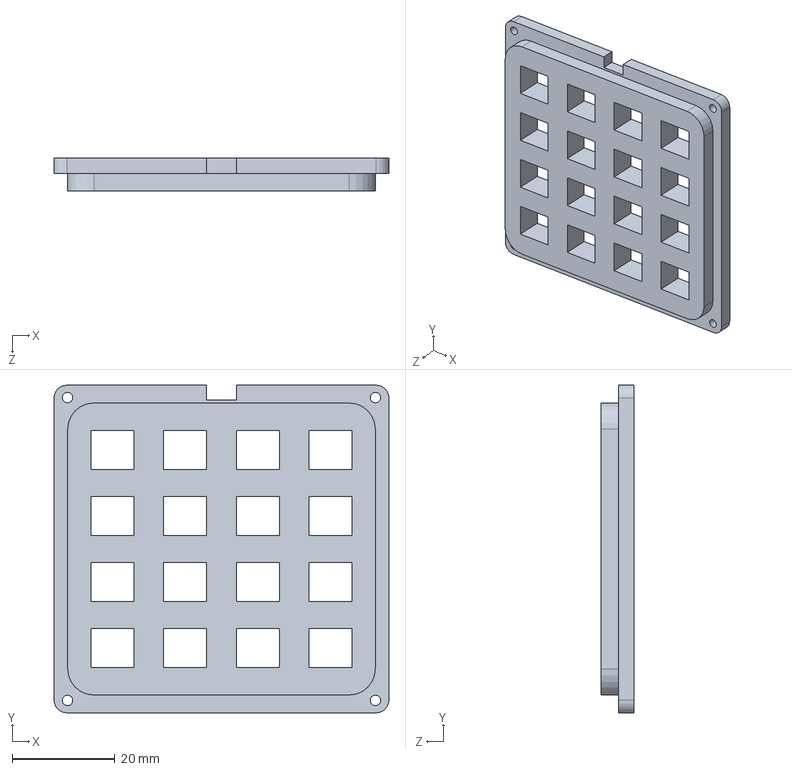
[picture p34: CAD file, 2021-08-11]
enclosure/plastic_base.SLDPRT
65.3 x 63.9 x 6.53 mm

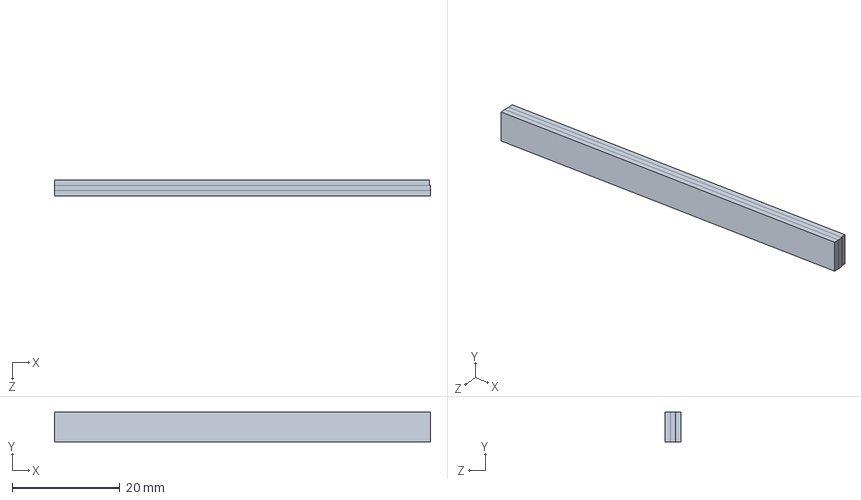
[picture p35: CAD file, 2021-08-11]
enclosure/conductor.SLDPRT
69.7 x 5.50 x 3.00 mm

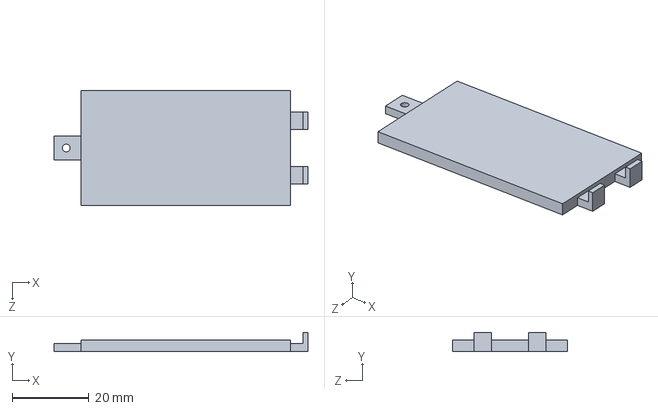
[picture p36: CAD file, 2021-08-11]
enclosure/holder cap.SLDPRT
66.1 x 5.00 x 30.0 mm

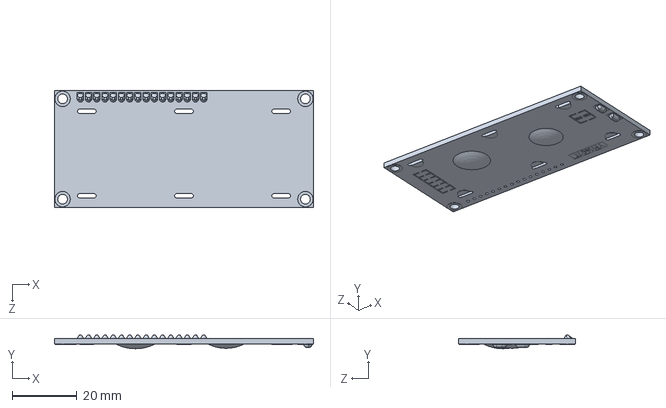
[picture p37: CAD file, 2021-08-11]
enclosure/pcbboard.SLDPRT
80.0 x 4.19 x 36.0 mm

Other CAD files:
enclosure/9v battery.stp
enclosure/smt_resistor101.sldprt
enclosure/backlight.SLDPRT
enclosure/pcb.SLDPRT
enclosure/16pin_header__.sldprt
enclosure/enclosure.SLDPRT
enclosure/liquid crystal grabcad.SLDPRT

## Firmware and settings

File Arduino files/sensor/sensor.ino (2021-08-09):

#include <Wire.h>
#include <LiquidCrystal_I2C.h>
#include <Keypad.h>

// Set the LCD address to 0x27 for a 16 chars and 2 line display
LiquidCrystal_I2C lcd(0x27, 16, 2);
int inp_led[] = {11, 12, 13};
int value = A0;//LDR input take analog value


String calibColor[] = {"Black", "White"};
String color[]={"Red","Green","Blue"};
int calibrater[3][2] = {{363, 892}, {356, 839}, {326, 833}};
int outvalue[] = {0, 0, 0};
int out_led[] = {A1, A2, A3};
String mode;
int out;
String key;

const byte ROWS = 4; //four rows
const byte COLS = 4; //three columns
char keys[ROWS][COLS] = {
  {'1', '2', '3', 'A'},
  {'4', '5', '6', 'B'},
  {'7', '8', '9', 'C'},
  {'*', '0', '#', 'D'}
};

byte rowPins[ROWS] = {2, 3, 4, 5}; //connect to the row pinouts of the keypad
byte colPins[COLS] = {6, 7, 8, 9}; //connect to the column pinouts of the keypad

Keypad keypad = Keypad( makeKeymap(keys), rowPins, colPins, ROWS, COLS );



void setup() {
  lcd.init();
  lcd.backlight();

  for (int i = 0; i < 3; i++) {
    pinMode(inp_led[i], OUTPUT);
  }

  pinMode(value, INPUT);

  for (int i = 0; i < 3; i++) {
    pinMode(out_led[i], OUTPUT);
  }

  Serial.begin(9600);
  lcd.clear();
  lcd.setCursor(0, 0);
  lcd.print("WELCOME :)");
  delay(1000);
  lcd.clear();
  lcd.setCursor(0, 0);
  lcd.print("Press");
  lcd.setCursor(0, 1);
  lcd.print("C to calibrate");
  delay(1000);
  lcd.clear();
  lcd.setCursor(0, 0);
  lcd.print("Press");
  lcd.setCursor(0, 1);
  lcd.print("D to sensor");
  delay(1000);
  lcd.clear();
  lcd.setCursor(0, 0);
  lcd.print("Press A to");
  lcd.setCursor(0, 1);
  lcd.print("use keypad value");

}


void loop() {
  mode = keypad.waitForKey();
  if (mode == "C") {
    calibrate();
  }
  else if (mode == "D") {
    sensor();
    screenout();
    ledout();
  }
  else if (mode == "A") {
    pad();
    ledout();

  }
  else {
    lcd.clear();
    lcd.setCursor(0, 0);
    lcd.print("Invalidinput");
    delay(500);
  }
  lcd.clear();
  lcd.setCursor(0, 0);
  lcd.print("Press C to");
  lcd.setCursor(0, 1);
  lcd.print("calibrate again");
  delay(1000);
  lcd.clear();
  lcd.setCursor(0, 0);
  lcd.print("Else Press D");
  lcd.setCursor(0, 1);
  lcd.print("to sensor");
  delay(1000);
  lcd.clear();
  lcd.setCursor(0, 0);
  lcd.print("Press A to");
  lcd.setCursor(0, 1);
  lcd.print("use keypad value");

}

void calibrate() {
  char key = keypad.getKey();
  lcd.clear();
  lcd.setCursor(0, 0);
  lcd.print("CALIBRATION");
  delay(500);
  for (int j = 0; j < 2; j++) {
    lcd.setCursor(0, 0);
    lcd.print("Show" + String(calibColor[j]) + "color" );
    lcd.setCursor(0, 1);
    lcd.print("press any key to continue");
    key = keypad.waitForKey();
    lcd.clear();
    lcd.setCursor(0, 0);
    lcd.print("CALIBRATING.....");
    for (int i = 0; i < 3; i++) {
      digitalWrite(inp_led[i], HIGH);
      delay(500);
      calibrater[i][j] = analogRead(value);
      delay(500);
      digitalWrite(inp_led[i],LOW);
      Serial.print(String(color[i]));
      Serial.print("=");
      Serial.print(calibrater[i][0]);
      Serial.print(",");
      Serial.print(calibrater[i][1]);
      Serial.println();
    }
    if (j != 1) {
      lcd.clear();
      lcd.setCursor(0, 0);
      lcd.print("CALIBRATION");
      delay(500);
    }
    else {
      lcd.clear();
      lcd.setCursor(0, 0);
      lcd.print("CALIBRATION DONE");
      delay(1000);
      lcd.clear();
      lcd.setCursor(0, 0);
      lcd.print(String(calibrater[0][0]) + "," + String(calibrater[0][1]));
      lcd.setCursor(8, 0);
      lcd.print(String(calibrater[1][0]) + "," + String(calibrater[1][1]));
      lcd.setCursor(0, 1);
      lcd.print(String(calibrater[2][0]) + "," + String(calibrater[2][1]));
      delay(1000);
    }

  }
}

void sensor() {
  lcd.clear();
  lcd.setCursor(0, 0);
  lcd.print("SENSORING .....");
  lcd.setCursor(0, 1);
  lcd.print("press any key to sensor");
  key = keypad.waitForKey();
  for (int i = 0; i < 3; i++) {
    digitalWrite(inp_led[i], HIGH);
    delay(1000);
    out = analogRead(value);
    delay(10);
    digitalWrite(inp_led[i], LOW);
    outvalue[i] = map(out, calibrater[i][0], calibrater[i][1], 0, 255);
    outvalue[i] = outvalue[i] < 0 ? 0 : outvalue[i] > 255 ? 255 : outvalue[i];

  }
  lcd.clear();
  lcd.setCursor(0, 0);
  lcd.print("Sensor DONE");
  delay(500);
}

void pad() {
  String rgbval = "";
  lcd.clear();
  lcd.setCursor(0, 0);
  lcd.print("Type R,G,B value");
  for (int i = 0; i < 11; i++) {
    if (i == 3 || i == 7) {
      lcd.print('/');
      continue;
    }
    char rgbno = keypad.waitForKey();
    lcd.setCursor(i, 1);
    lcd.print(rgbno);
    rgbval += rgbno;
  }
  for (int i = 0; i < 3; i++) {
    outvalue[i] = rgbval.substring(3 * i, (3 * i + 3)).toInt();
  }

}
void screenout() {
  lcd.clear();
  lcd.setCursor(0, 0);
  lcd.print("R=" + String(outvalue[0]));
  lcd.setCursor(7, 0);
  lcd.print("G=" + String(outvalue[1]));
  lcd.setCursor(0, 1);
  lcd.print("B=" + String(outvalue[2]));

  delay(1000);
}
void ledout() {
  for (int i = 0; i < 3; i++) {
    analogWrite(out_led[i], outvalue[i]);
  }
  delay(1000);
  for (int i = 0; i < 3; i++) {
    digitalWrite(out_led[i], LOW);
  }
}

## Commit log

2021-06-07 Add files via upload
    ardiuno code for rgb sensor
2021-06-08 Final PCB Final Added
    [PCB.pcbdoc, color Sensor_Schematic.schdoc]
2021-06-08 Create README.md
    PCB online link ( Easy EDA ) added
2021-06-08 PCB solidwork step file added
2021-06-08 Pcb altium file added
    [PCB.pcbdoc]
2021-06-09 Routing updated PCB Altium file added
    [updated PCB_color Sensor Grp 14.pcbdoc]
2021-08-09 Missing Arduino files added
    [sensor.ino]
2021-08-15 Add Final Works
    [PCB FINAL VERSION.pcbdoc, PCB Main.step, PCB_1.pcbdoc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]
